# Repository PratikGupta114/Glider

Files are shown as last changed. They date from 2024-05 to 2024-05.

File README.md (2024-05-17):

<p align="center">
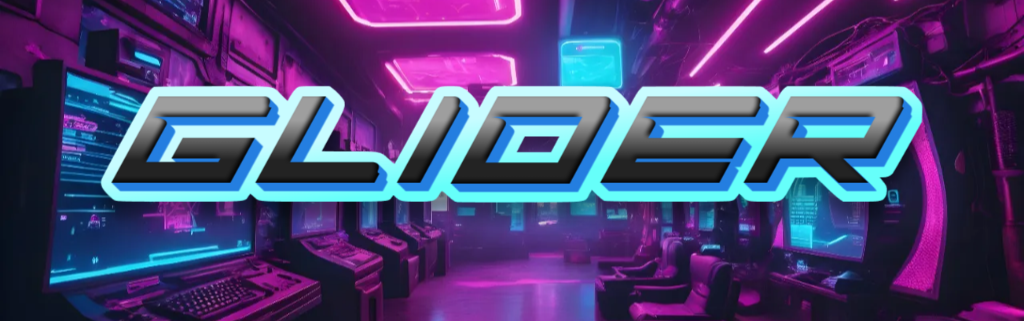
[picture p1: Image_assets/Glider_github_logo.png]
    
</p>

<p align="center">
    
</p>

<p align="center">
    
</p>

</br>

# Project Glider  
The official github repository for all Glider boards comprising Documentation, Pinouts & Example Sketches for all applications built using Glider boards.

The Glider Project is an initiative by the HyperDrive Community to make robotics accessible to everyone. It provides the necessary electronics for building quality robots and offers open-source code for projects that can be built using this board.

## A yet another Robo board ?

The Glider board solves a very common problem faced in robotics : 

> ***"Building robot boards from scratch"*** 

Although building a Robot board from scratch is fun, however it isn't necessary to **re-invent the wheel**.

Creating a DIY robot board is often tedious, time-consuming and error-prone, and such errors can be costly. Additionally, constructing the electronics for a robot is time-consuming. Even after successfully creating a DIY robot board on a zero-PCB (also known as a vero board), the board may lack sufficient connectivity, required for other projects.

## More about Glider boards 

Glider boards help makers and electronics hobbyists build amazing robots by providing connectivity for mutiple peripherals on a single pcb, such as:

* 2x 12V DC brushed motors (with connectivity for individual encoders for each motor)
Buttons
* 0.96" I2C OLED display
* MPU6050
* Buzzer & WS2812B Neopixels
* UART-based devices like HC-05
* Any 5V I2C-based peripheral
* In addition to providing connectivity with multiple peripherals, Glider boards offer reverse polarity protection at the source and support a wide voltage supply range of 7V to 20V.

Following are the links to the detailed documentation of all the Glider boards developed so far. 

- [Glider v1.0](./Docs/Glider_v1.0/doc.md) 

## Directory Structure

The following tree shows how the files are arranged in dedicated folders for easier navigation.

```
Glider/   
├─ 3D_models/  
│  ├─ [BOARD_NAME_1]/  
│  │  ├─ [STEP_FILE_1].step  
│  │  ├─ [STEP_FILE_2].step  
│  ├─ [BOARD_NAME_2]/  
├─ Code_examples/  
│  ├─ [BOARD_NAME_1]/  
│  │  ├─ Arduino_projects/  
│  │  │  ├─ [PROJECT_NAME_1]/  
│  │  │  ├─ [PROJECT_NAME_2]/  
│  │  ├─ PlatoformIO_projects/  
│  │  │  ├─ [PROJECT_NAME_1]/  
│  │  │  ├─ [PROJECT_NAME_2]/  
│  ├─ [BOARD_NAME_2]/  
├─ Docs/  
│  ├─ [BOARD_NAME_1]/  
│  │  ├─ [DOC_1].md  
│  │  ├─ [DOC_2].md  
│  ├─ [BOARD_NAME_2]/  
├─ Image_assets/  
LICENSE  
README.md  
```

## About Hyper Drive Community

Hyper Drive is a community of like-minded robotics enthusiasts who aim to guide and motivate young engineers in building and breaking barriers to create new robots.

We as community organizers, offer guidance in building autonomous bots and resources, such as articles, discussions, and expert mentorship, to those struggling to make their robots work.
HyperDrive\'s philosophy is centered around the idea of technology as a sport .We aim to bring together a diverse community of innovators, engineers, inventors, enthusiasts, and competitors under one roof.

We are passionate about motivating young engineers to create new robots, break through barriers, and strive for excellence in competition.
Join us today and discover the endless possibilities of robotics. 
No prior experience is necessary, and we welcome all levels of enthusiasts who share our commitment to learning and enthusiasm for engineering. HyperDrive is an initiative to provide you with what we never had during our time, 
and we invite you to be part of this exciting journey.

<br/>

<div align="center">
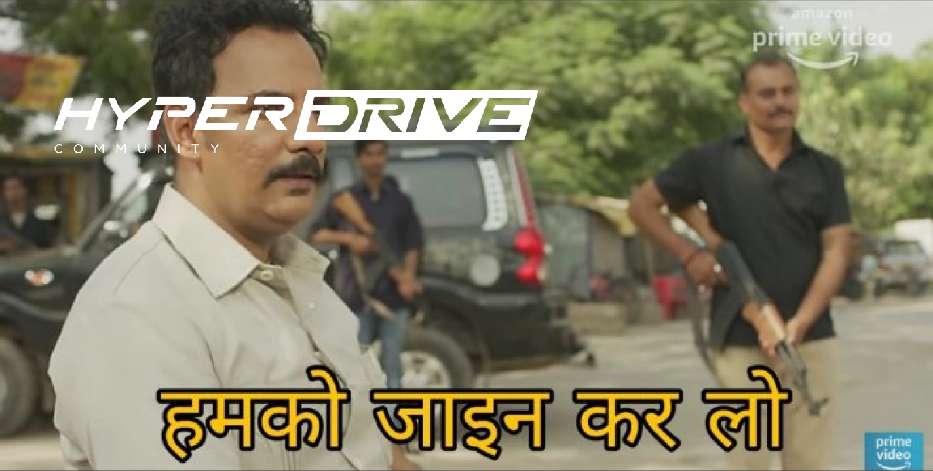
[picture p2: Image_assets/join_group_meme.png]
    
</div>

<br/>

<div align="center">  
    <a href="https://t.me/hyperdrivehd">
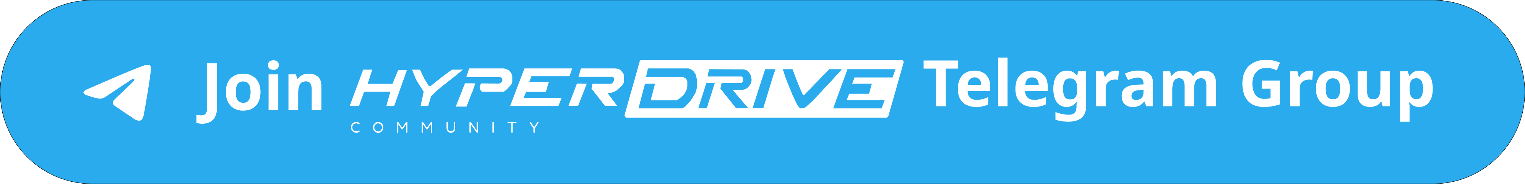
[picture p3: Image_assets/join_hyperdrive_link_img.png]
        
    </a>
</div>

## Author

<div align="center">
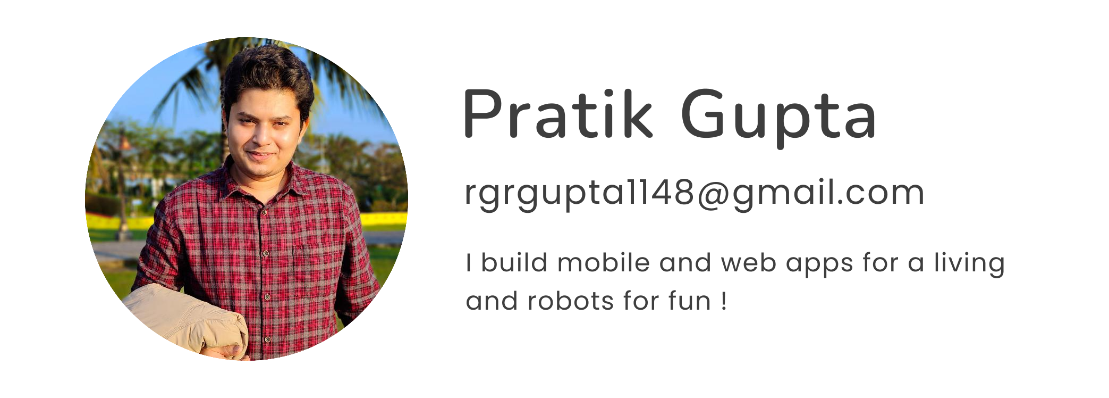
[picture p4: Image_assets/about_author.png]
    
</div>

<br/>
<br/>

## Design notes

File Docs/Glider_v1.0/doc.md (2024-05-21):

<div align="center"> 
     
</div>

</br>

# Glider v1.0

The first version of the Glider board series. A versatile, ESP32 powered, robot control board that allows one to build amazing robots. This board comes along with other components in form of a kit.

Apart from the roboboard, the other components include :

* [12 channel Line Sensor Array](#12-channel-line-sensor-array)
* [Parallel to Serial adapter for Line Sensor Array](#parallel-to-serial-adapter-for-line-sensor-array)
* [Neopixel Array & Buzzer board](#neopixel-array--buzzer-board)
* [OLED based GUI board](#oled-based-gui-board)

One of the common applications of this kit is Line Follower / Maze Solver robot. Apart from the components mentioned above, the kit also includes the necessary JST cables for enabling connectivity between the boards.

## The Roboboard 

<br/>

<p align="center">
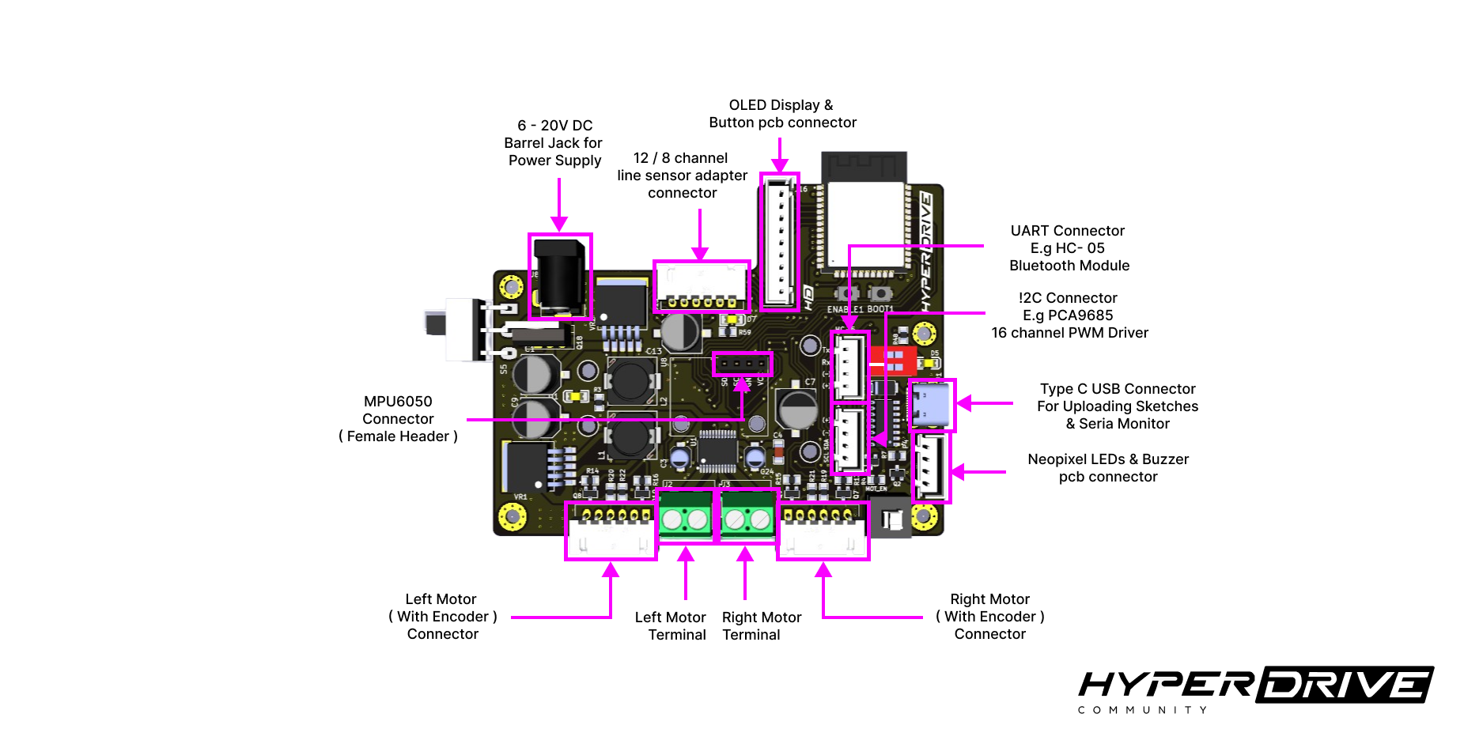
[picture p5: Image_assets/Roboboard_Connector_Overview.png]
    
</p>

<br/>

<p align="center">
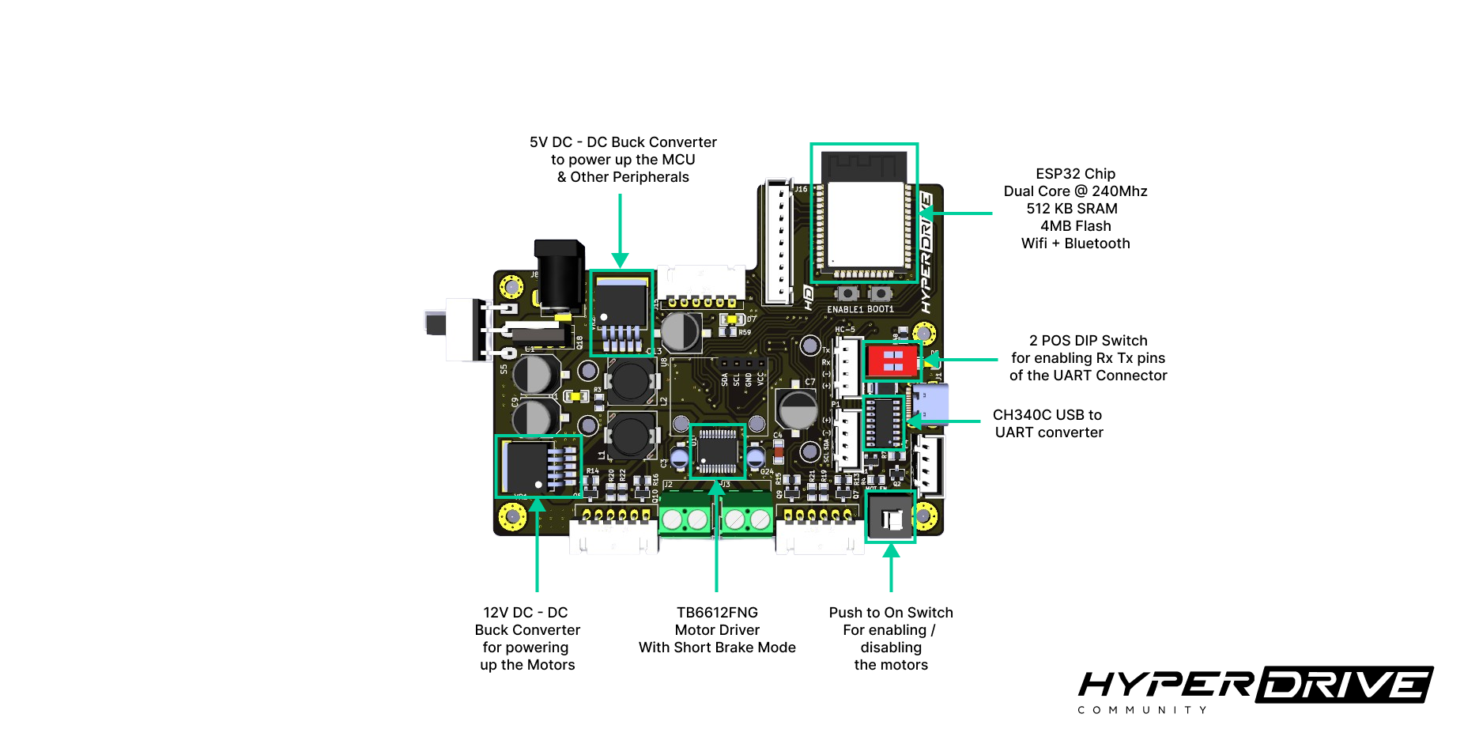
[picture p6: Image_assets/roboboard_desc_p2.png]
    
</p>

<br/>

Like most roboboards, the Glider v1.0 board too has a microcontroller and a motor driver However, this board has a lot more than just two of these components. Following are the core features of the roboboard : 

### 1. Wide range power supply 

this roboard has two buck converters : 12V and 5V. This way the board can be powered by upto 20V via the DC barrel jack.

### 2. USB Type C connectivity 

Unlike most arduino boards, like uno and nano, this has a type C USB connector for uploading the code to ESP32 and serial monitoring.

### 3. Mosfet based TB6612FNG motor driver

known for it's efficiency and decent current output of 1.2A per channel (continous & 3A peak), this board Has the widely used Tb6612fng motor driver integrated on board.

### 4. Encoder Motor Connectivity 

besides scew terminal blocks for controlling two independently running DC motors, the board has two connectors for motors with encoders. ***It's important to note that the first two pins of the connector (close to the terminal blocks) are connected to the screw terminals***.

### 5. Connectivity for MPU6050 

besides having encoders for obtaining odomentry data, the robot may need an IMU for better position estimation. The roboboard has a connectivity for an MPU6050, positioned in a way that the IMU is present at the center.

### 6. Connectivity for HC-05

ESP32 has an inbuilt WiFi and Bluetooth connectivity, however this communication is managed by the code. Such wireless connections may fail to persist after the micrcocontroller resets. To enble wireless debugging over bluetooth, the roboboard has the connectivity for an external module like the HC-05.

### 7. Neopixels (WS2812B RGB LED) array with buzzer 

most robots have to indicate the occurence of an event like detecting a checkpoint ( in case of a line follower ) or detecting a valid intersection ( in case of a maze solvinf robot). The kit comes along with a pcb strip which includes an array of 6 WS2812B leds and a buzzer for unique audio and visual indications.

### 8. Additional Connectivity for I2C based devices  

many projects may require the board to interface with external I2C based peripherals like sensors & motors controllers. Once such example could be PCA9685 for controlling multiple servo motors. Thus projects like a hexapod or a bipedal humanoid robot can also be built using this roboboard.

### 9. 3.3V to 5V transaltion  

Circuitry for conversion of logic level from 3.3v to 5v and vice-versa exists. All the pins the ESP32 board are connected to MOSFET based logic level converters / translators for safe interfaction with 5V logic level devices.

### 10.  GUI board with OLED display connectivity 

The kit includes a GUI board with 4 smd button arranged in Top, Left, Right & Bottom configuration. The board also includes the debouncing circuitry for each of the 4 buttons. Besides, the GUI board has a connectivity for a 0.96" OLED display, hence providing a GUI setup for users to make necessary configurations on the robot dynamically.   

### 11. Easy Motor Driver Control  

The board has a push to On / Off switch for enabling / disabling the motor driver. The TB6612FNG has a STBY pin that allows it to be enabled / disabled by applying +5V digital logic ( 1 or 0). This pin is connected to +5V via a push to on / off switch that haults the motors without affecting the microcontroller's operation and powering off the entire board. This feature comes handy in many scenarious specially in case of a Line Follower Robot.  

### 12. Firm Connections to ensure reliabiity 

Unline most arduino based DIY projects, the use of Jumper / dupont wires may often lead to undesirable behavior as such connecting wires are prone to wearing out over multiple connections / disconnections. Japan Solderless Terminals (JST) connectors on the other hand are widely used in the industry, specially in most electronics based products due to their reliable nature. Leveraging this reliability and firm connectivity JST connectors are used throughout to allow firm connections as jumper wires are often fragile and wear out over time.

## Roboboard ESP32 pin allocation table

The following table describes which of the ESP32 GPIO pins are allocated to the onboard peripherals, however one can refer to the [Diagram based pinout](/Image_assets/roboboard_pinout.png) for convenience

| ESP32 pin in ESP-IDF | Peripheral  |  3.3V to 5V Translation  |
| --- | --- | ---  |
<br/><span style="font-weight:bold;font-size:1.15em">Motor Driver (TB6612FNG)</span>
|   ```GPIO_NUM_26```  | AIN1 | Yes    |
|   ```GPIO_NUM_25```  | AIN2 | Yes    | 
|   ```GPIO_NUM_32```  | BIN2 | Yes    |
|   ```GPIO_NUM_33```  | BIN1 | Yes    |
|   ```GPIO_NUM_19```  | PWMA | Yes    |
|   ```GPIO_NUM_18```  | PWMB | Yes    |
<br/> <span style="font-weight:bold;font-size:1.15em">Line Sensor Adapter connectivity port</span>
|   ```GPIO_NUM_27```  | LOAD_PIN           | Yes  | 
|   ```GPIO_NUM_4```   | CLOCK_ENABLE_PIN   | Yes  |
|   ```GPIO_NUM_17```  | DATA_PIN           | Yes  |
|   ```GPIO_NUM_16```  | CLOCK_PIN          | Yes  |
<br/> <span style="font-weight:bold;font-size:1.15em">On board peripherals</span>
|   ```GPIO_NUM_2```   | BLUE_LED | No |
<br/> <span style="font-weight:bold;font-size:1.15em">Indication Board connectivity port</span>
|   ```GPIO_NUM_12```  | BUZZER             | Yes  |
|   ```GPIO_NUM_23```  | NEOPIXEL_LED_PIN   | Yes  |
<br/> <span style="font-weight:bold;font-size:1.15em">GUI Board connectivity port</span>
|   ```GPIO_NUM_36```  | BUTTON_LEFT    | No   |        
|   ```GPIO_NUM_39```  | BUTTON_RIGHT   | No   |       
|   ```GPIO_NUM_34```  | BUTTON_TOP     | No   |       
|   ```GPIO_NUM_35```  | BUTTON_BOTTOM  | No   |      
<br/> <span style="font-weight:bold;font-size:1.15em">Encoders port</span>
|   ```GPIO_NUM_15```  | LEFT_MOTOR_ENC_A   | Yes  |
|   ```GPIO_NUM_5```   | LEFT_MOTOR_ENC_B   | Yes  |
|   ```GPIO_NUM_13```  | RIGHT_MOTOR_ENC_A  | Yes  |
|   ```GPIO_NUM_14```  | RIGHT_MOTOR_ENC_B  | Yes  |
<br/> <span style="font-weight:bold;font-size:1.15em">I2C ports</span>
|   ```GPIO_NUM_21```  | SDA_PIN | Yes |
|   ```GPIO_NUM_22```  | SCL_PIN | Yes |
<br/> <span style="font-weight:bold;font-size:1.15em">UART0 ( Serial0 )</span>
|   ```GPIO_NUM_1```  | TXD_0   | No   |
|   ```GPIO_NUM_3```  | RXD_0   | No   |

<br/>

## 12 channel Line Sensor Array

<br/>

<p align="center">
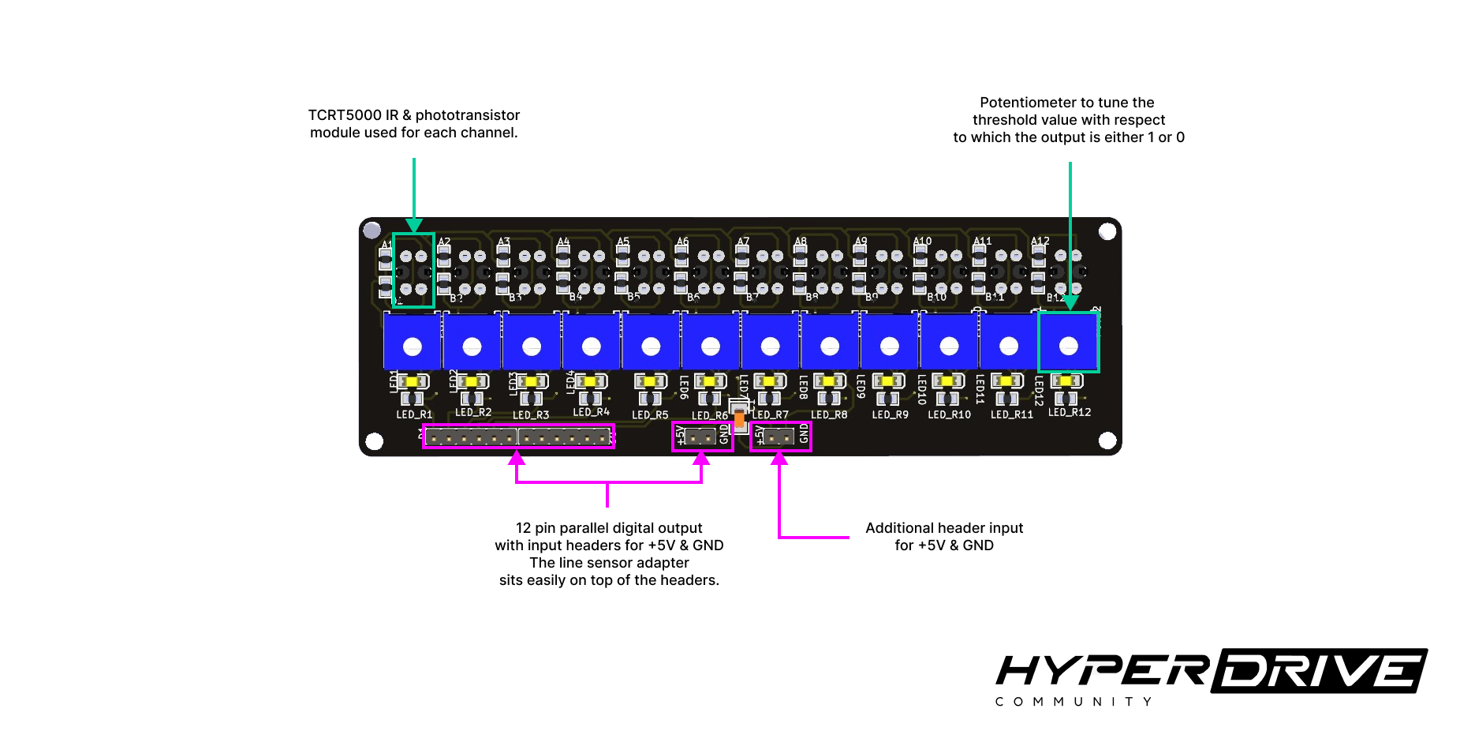
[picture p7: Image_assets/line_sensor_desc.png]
    
</p>

<br/>

This sensor array has 12 individual sensors that output either +5V / 0V (digital 1 / 0) depending on how white / black the surface beneath the sensor is. The threshold above which the sensor outputs 1, is adjusted by the corresponding potentiometer. This way the Line sensor array outputs a 12 bit digital data.

Since the sensor ouputs 1 for a white surface and 0 for black surface, then sliding the sensor above a white line ( which is drawn above the black surface ), thick enough to cover 2 sensors, them the 12 bit output from the sensors looks something like : 

```
001100000000
000110000000
000011000000
000001100000
000000110000
000000011000
000000001100
```

## Parallel to Serial adapter for Line Sensor Array

A microcontroller may not have enough digital pins to read all the 12 bits of data from the line sensor array. This parallel output from the line sensor array must be converted to serial data such that the microcontroller can interface with the sensor using only a few pins. 
One such device for reading multiple inputs, using only 4 gpio pins of a microcontroller, is a shift register.  

For instance, an 8 bit shift regsiter, like 74HC165, can read upto 8 digital inputs. Hence for reading the 12 bit data from the line sensor array, at least two of these 8-bit shift registers will be required.
74HC165 shift registers have the ability to be cascaded with another shift register in a way that using only one data pin, a microcontroller can read data from all the shift registers. 

The adapter pcb houses two *daisy chained* shift registers and the serial output connector has the necessary pins that allows any microcontroller to read the Serial data. 
As shown in the [pinout](/Image_assets/adapter_pinout.png), the adapter outputs 16-bit data out of which 12 bits in the middle represent the digital output from the line sensor array and two bits from either side are dummy bits.

<br/>

<p align="center">
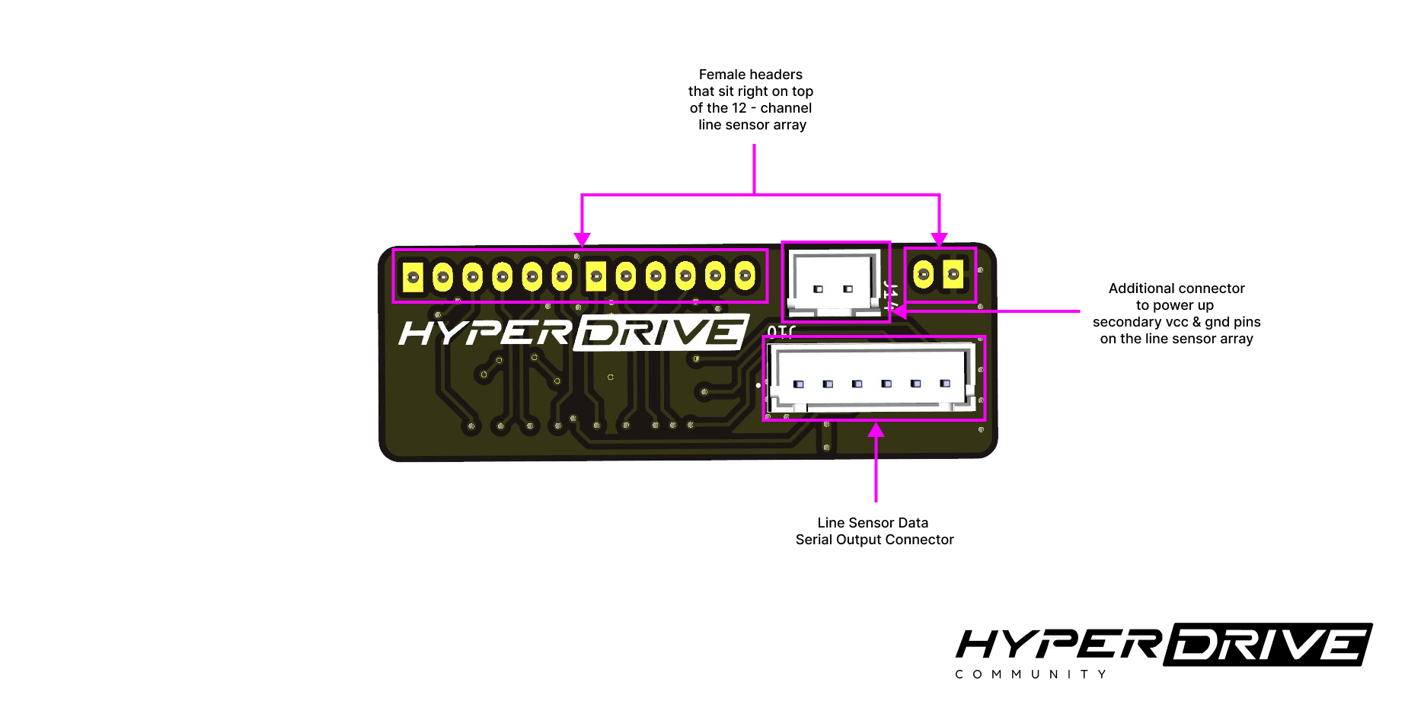
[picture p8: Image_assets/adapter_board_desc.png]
    
</p>

## Neopixel Array & Buzzer board

This board is a smalll pcb strip which has 6 WS2812B Neopixel RGB LEDs and a 5V buzzer. As shown in the [pinout](/Image_assets/indication_board_pinout.png), the connector with 4 pins acts as the input for the first neopixel leds and the buzzer. This board also has an output to extend the chain of LED array. Thus allowing an LED string to be connected with this board. However it is important to note that this board may have a limited ouput power. Thus limiting the number of LEDs that can be extended with this board.  

<br/>

<p align="center">
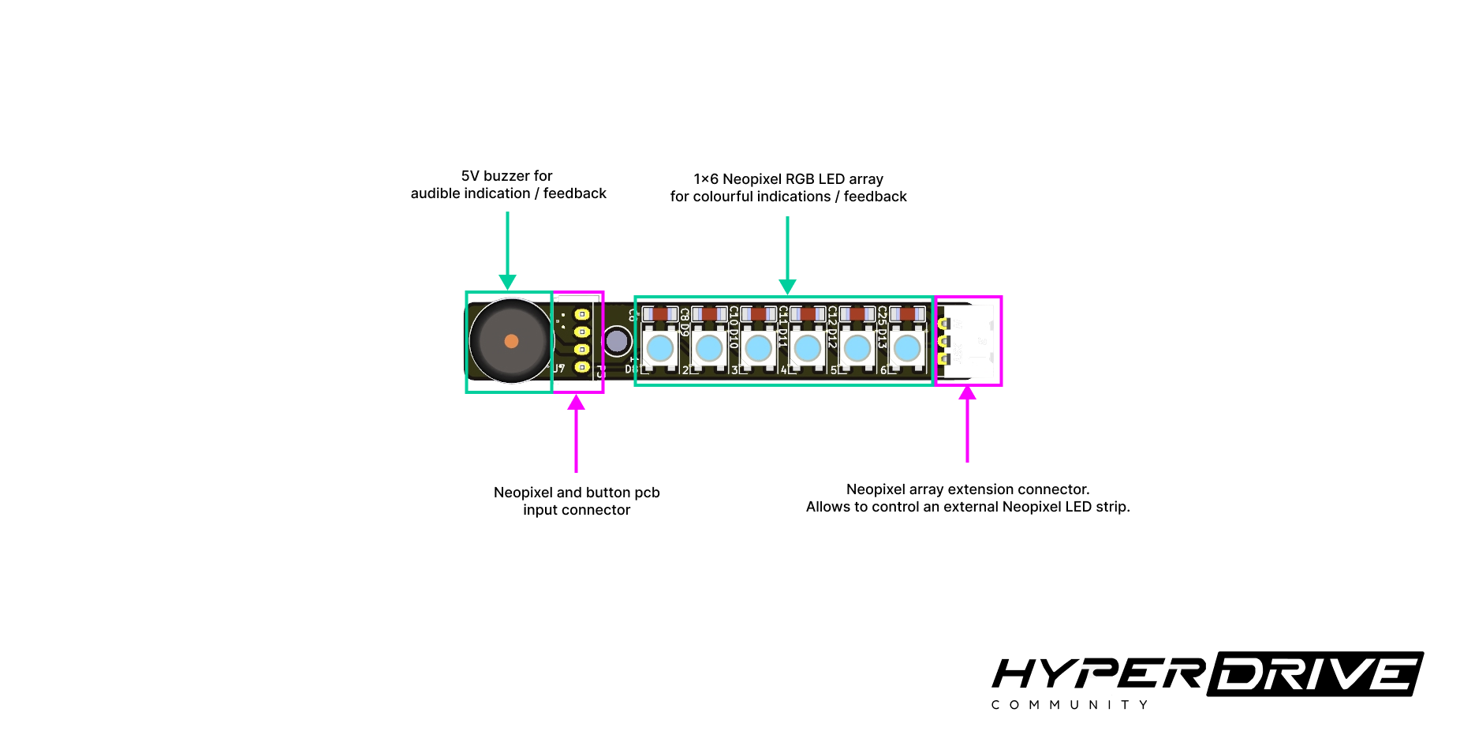
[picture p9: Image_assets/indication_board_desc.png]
    
</p>

<br/>

## OLED based GUI board

A robot built with the Glider v1.0 may require configurations to made dynamically, in other words, configurations without re-uplaoding the firmware. Such frequent configurations can be made either wirelessly, or via an onboard GUI. This roboboard is capbale of implementing both the approach. However, an onboard GUI doesn't always require a persistent wireless connection.

This GUI board has 4 smd button which can help users to navigate through a menu, which can possibly be displayed on a SSD1306 OLED display. To ensure robustness and utilize the pcb-real estate, this board also includes required circuitry for button debouncing allowing interrupt based programs can run flawlessly.

On the left side of the pcb, female headers are present to allow SSD1306 based OLED displays to connect. Therefore this board serves most functionalities of a GUI board. Besides, the outline of this board is designed in such a way that it can be stacked up on the robobaord using 4 nuts, bolts, and spacers and connect with the roboboard via a 9 pin JST cable. Please check the [pinout](/Image_assets/gui_board_pinout.png) for the gui board connector.

<br/>

<p align="center">
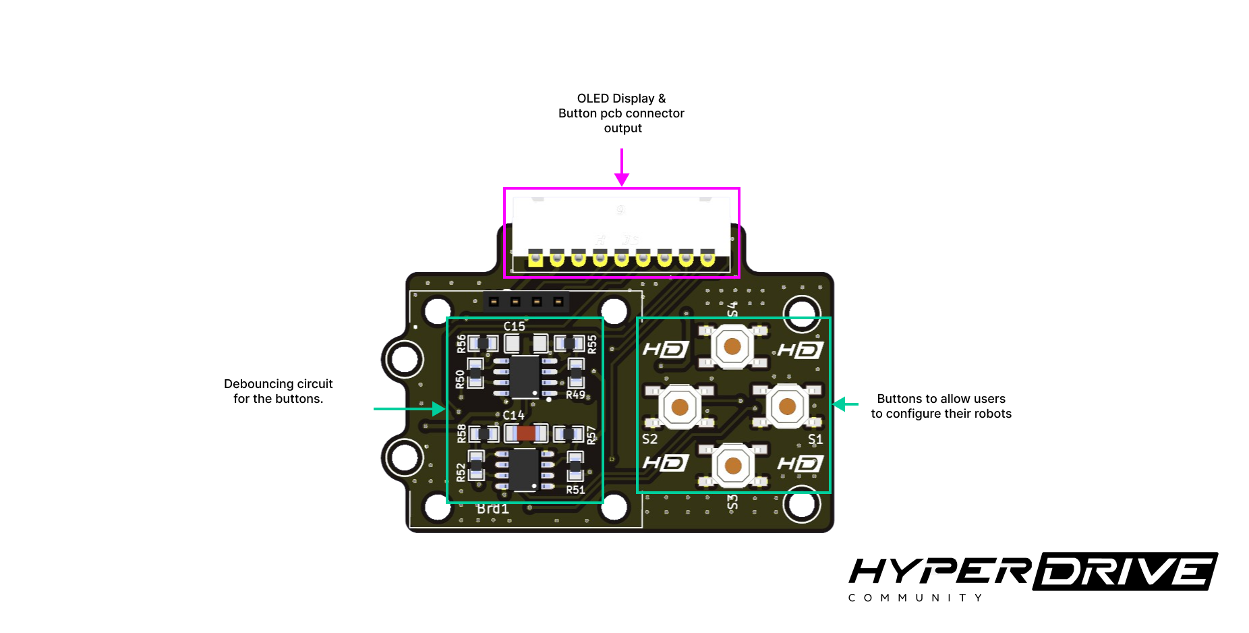
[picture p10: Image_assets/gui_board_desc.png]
    
</p>

<br/>

## Pinouts 

Following are the links to the images that describe each of the pins of the connectors on the respective boards : 

1. [Roboboard pinout](/Image_assets/roboboard_pinout.png)
2. [Line sensor adapter pinout](/Image_assets/adapter_pinout.png)
3. [Indication pinout](/Image_assets/indication_board_pinout.png)
4. [GUI board pinout](/Image_assets/gui_board_pinout.png)

## Projects 

Unlike most roboboards designed for specific project. The Glider v1.0 board allows users to build several other robots like : 
* Hexapod 
* Quadcopter
* Self-balancing robot

However, Line Following robots are the entry point to get started with robotics. The kit comes along with a 12 channel line sensor array which allows makers to build a Line Follower Robot. This repository contains the [source code for an LFR](/Code_examples/Glider_v1.0/PlatformIO_projects/Line_Follower_Robot/), as a platformIO project, and the same for other projects to get started.

Line Follower Robot In Action

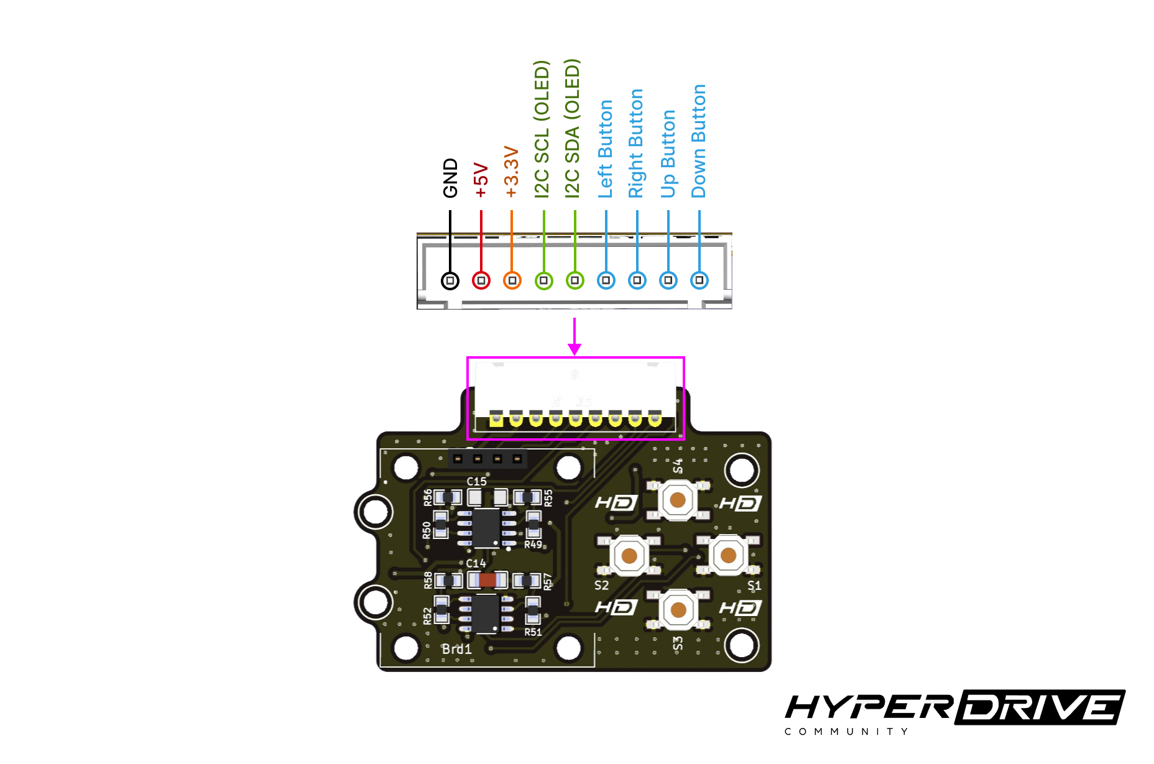
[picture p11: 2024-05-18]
Image_assets/gui_board_pinout.png

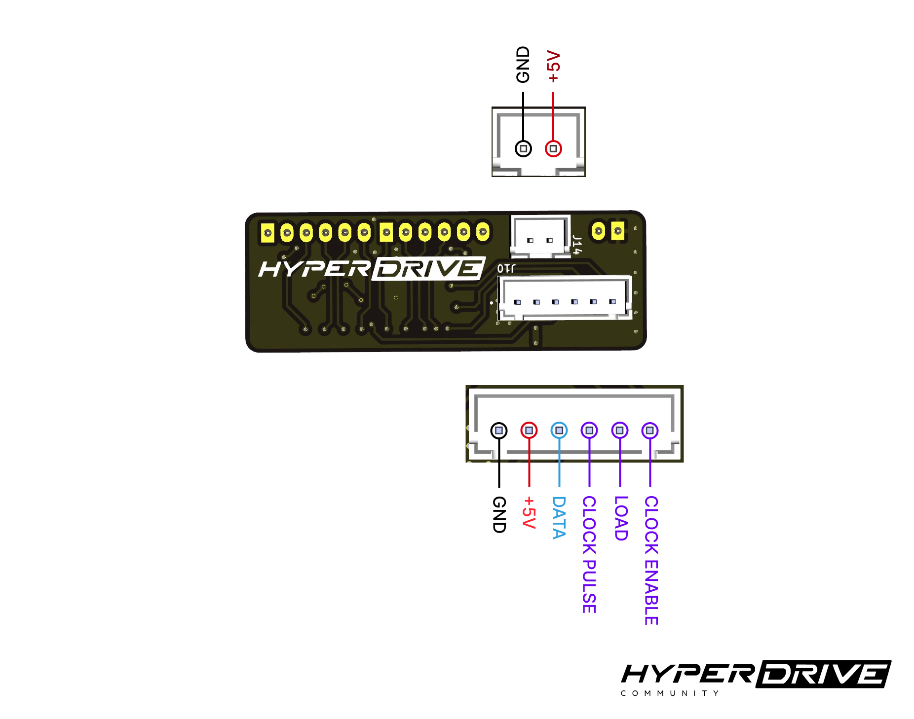
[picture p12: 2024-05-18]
Image_assets/adapter_pinout.png

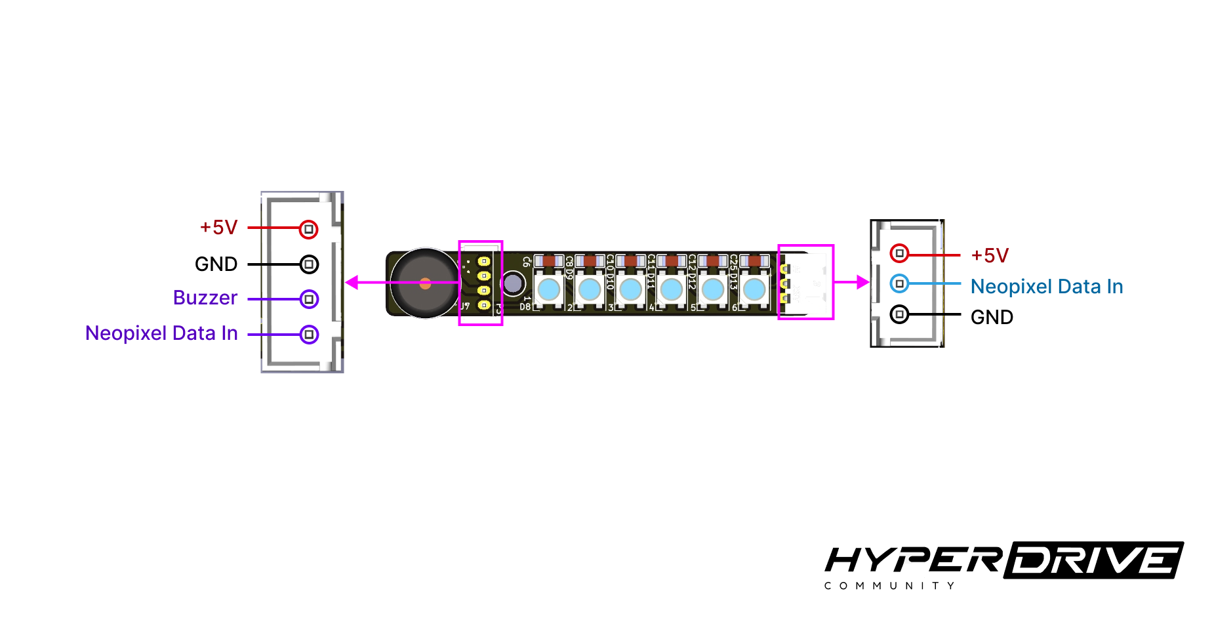
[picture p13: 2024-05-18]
Image_assets/indication_board_pinout.png

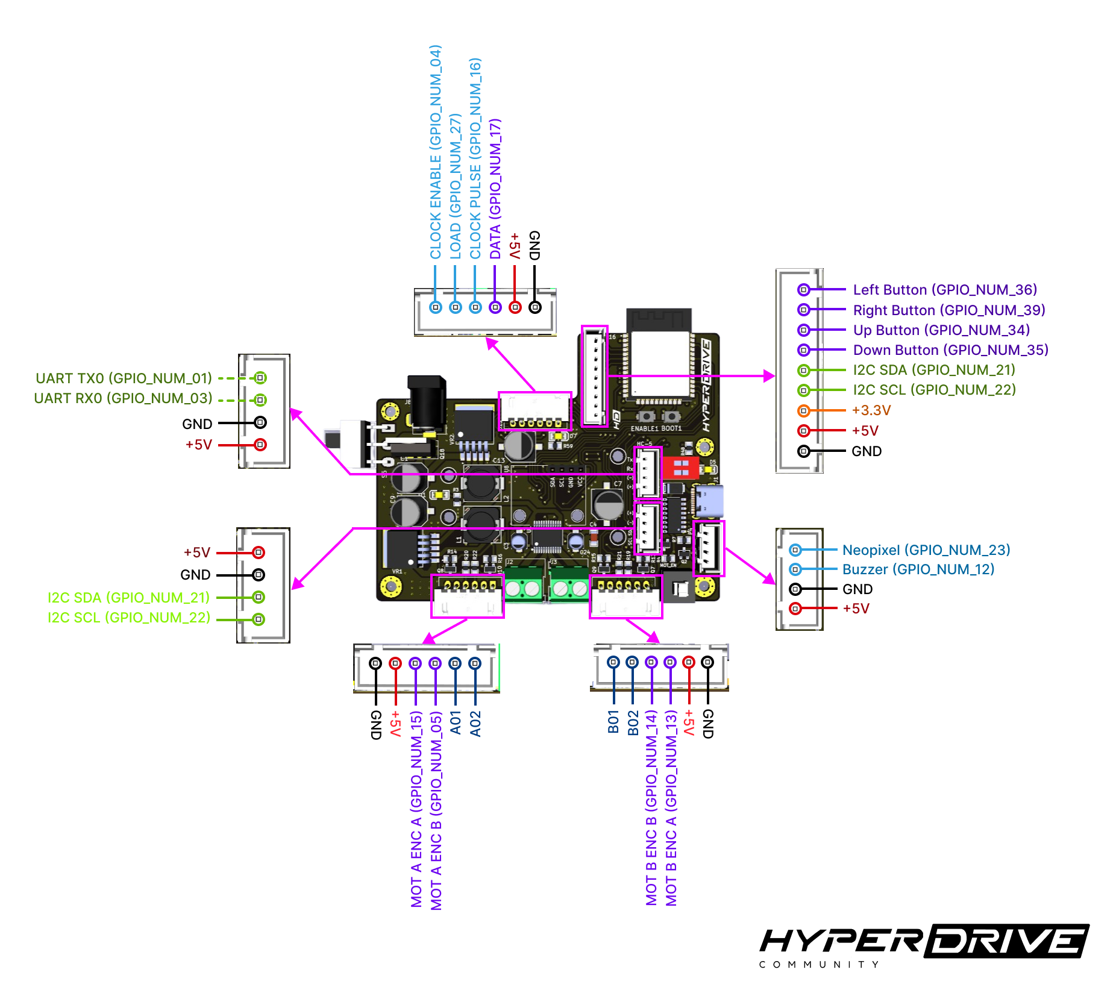
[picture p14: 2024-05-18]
Image_assets/roboboard_pinout.png

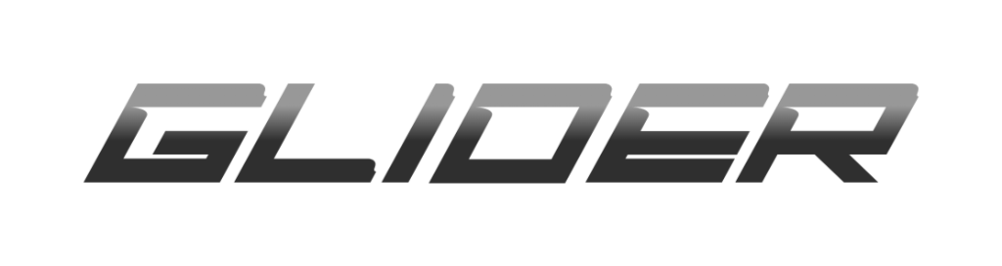
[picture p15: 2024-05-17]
Image_assets/gLIDER-15-05-2024 (2).png

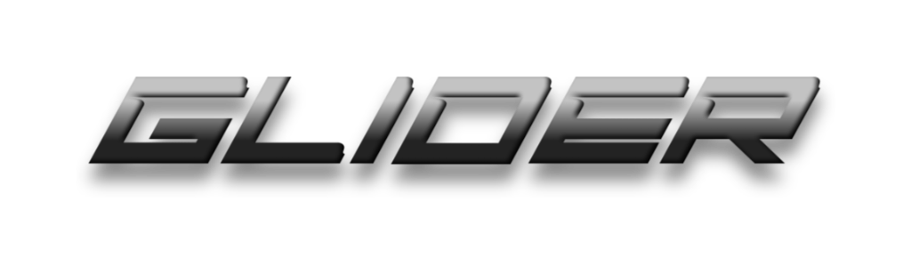
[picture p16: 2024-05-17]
Image_assets/gLIDER-15-05-2024 (3).png

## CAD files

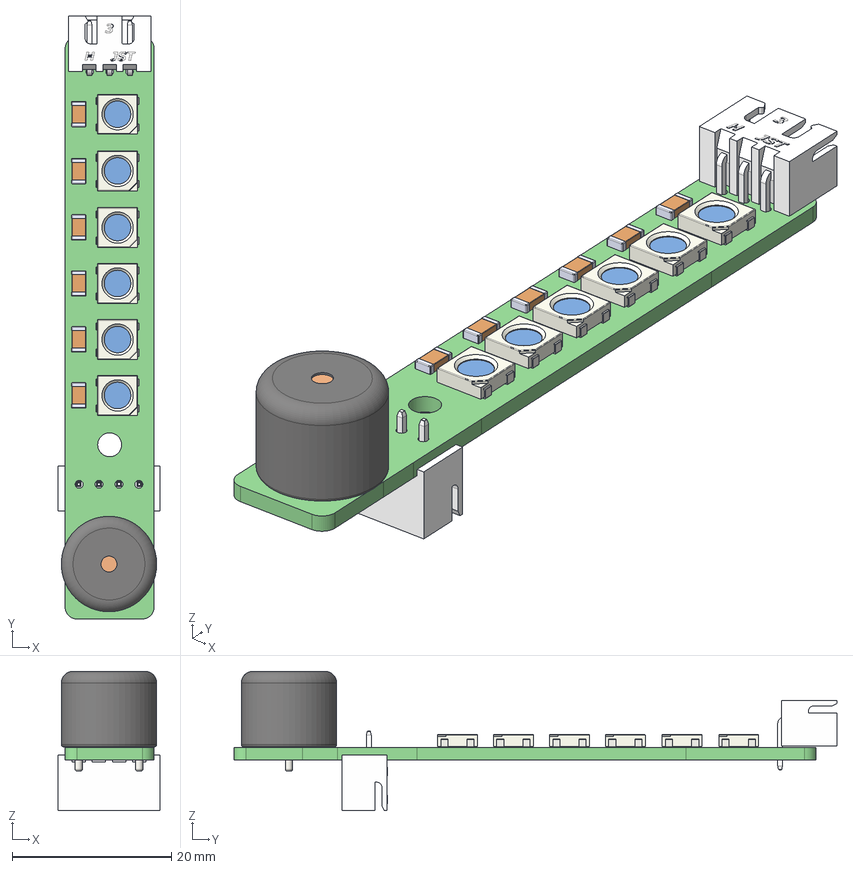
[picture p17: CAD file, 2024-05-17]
3D_models/Glider_v1.0/LFRControlBoard_Indicator.step
12.9 x 75.8 x 17.5 mm

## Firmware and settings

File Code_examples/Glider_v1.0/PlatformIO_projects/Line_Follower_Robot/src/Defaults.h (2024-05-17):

#ifndef DEFAULTS_H
#define DEFAULTS_H

#define OUT_OF_LINE_ERROR_VALUE 20
#define LOOP_ESCAPE_ERROR_VALUE 3

// The duration in milliseconds for which the short brake is applied.
#define BRAKE_DURATION_MILLIS 100

#define DEFAULT_LOOP_DELAY 0
#define DEFAULT_KP 0
#define DEFAULT_KI 0
#define DEFAULT_KD 0
#define DEFAULT_MOTOR_SPEED 0
#define WHITE_LINE_BLACK_TRACK 0
#define BLACK_LINE_WHITE_TRACK 1

// Percentage by which the base motor speed reduces
// whenever the robot rotates clockwise / counter clockwise.
#define TURN_SPEED_REDUCTION_PERCENT 10

// The duration in milliseconds for which the robot moves straight to
// confirm the presence of a stop patch.
#define STOP_CHECK_DELAY 150

#endif

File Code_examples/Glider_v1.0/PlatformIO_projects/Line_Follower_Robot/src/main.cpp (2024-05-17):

#include <Arduino.h>
#include "PinDefinitions.h"
#include "Config.h"
#include "Defaults.h"
#include "GlobalVariables.h"
#include "MotorControl.h"
#include "Sensor.h"
#include "Wire.h"
#include "FastLED.h"

// Include ArduinoJson.h only when bluetooth logging / tuning is enabled.
#if BLUETOOTH_LOGGING_ENABLED == 1 || BLUETOOTH_TUNING_ENABLED == 1
#include <ArduinoJson.h>

#define TX_DOC_MAX_DATA_LEN 256
#define RX_DOC_MAX_DATA_LEN 192

// Inlcude BluetoothSerial.h only when the config macro for using the inbuilt bluetooth is set to 1
#if USE_INBUILT_BLUETOOTH == 1
#include <BluetoothSerial.h>

#endif
#endif

// Macro definitions for commonly occurring conditions.
// These macro definitions make the code more readable.
#define MID_8_SENSORS_HIGH (s3 == 1 && s4 == 1 && s5 == 1 && s6 == 1 && s7 == 1 && s8 == 1 && s9 == 1 && s10 == 1)
#define MID_8_SENSORS_LOW (s3 == 0 && s4 == 0 && s5 == 0 && s6 == 0 && s7 == 0 && s8 == 0 && s9 == 0 && s10 == 0)

#define MID_6_SENSORS_HIGH (s4 == 1 && s5 == 1 && s6 == 1 && s7 == 1 && s8 == 1 && s9 == 1)
#define MID_6_SENSORS_LOW (s4 == 0 && s5 == 0 && s6 == 0 && s7 == 0 && s8 == 0 && s9 == 0)

// #########################################################################################################################
///////////////////////////////////////////////     VARIABLE DEFINITIONS     ///////////////////////////////////////////////
// #########################################################################################################################

#if BLUETOOTH_LOGGING_ENABLED == 1
StaticJsonDocument<TX_DOC_MAX_DATA_LEN> txDoc;
#endif
#if BLUETOOTH_TUNING_ENABLED == 1
StaticJsonDocument<RX_DOC_MAX_DATA_LEN> rxDoc;
#endif

int Kp = DEFAULT_KP;
int Ki = DEFAULT_KI;
int Kd = DEFAULT_KD;
int baseMotorSpeed = DEFAULT_MOTOR_SPEED;
int loopDelay = DEFAULT_LOOP_DELAY;
int error = 0;
int leftMotorOffset = 0;
int rightMotorOffset = 0;
int P = 0;
int I = 0;
int D = 0;
int error_dir = 0;
int previousError = 0;
int PID_value = 0;

// Make sure to update this variable according to the type of track the LFR is about to run on.
// When the macro for enabling inversion is set to 1, this variable updates itself automatically.
uint8_t trackType = BLACK_LINE_WHITE_TRACK;

CRGB leds[NUM_LEDS];

// Define the Inbuilt bluetooth object only when bluetooth tuning / logging config macro is set to 1
// and the default bluetooth is to be used.
#if ((BLUETOOTH_LOGGING_ENABLED == 1 || BLUETOOTH_TUNING_ENABLED == 1) && USE_INBUILT_BLUETOOTH == 1)
BluetoothSerial SerialBT;
#endif

// #########################################################################################################################
///////////////////////////////////////////////     FUNCTION DEFINITIONS     ///////////////////////////////////////////////
// #########################################################################################################################

/**
 * @brief 	This function is called when inversion is enabled and the trackType variable changes to
 * 			the type different from the default value.
 * 			In this case, 2 out of 6 LEDs of the Neopixel array indicate red for inversion and the
 * 			rest are for indicating checkpoints.
 */
void indicateInversionOn()
{
	leds[0] = CRGB(255, 0, 0);
	leds[1] = CRGB(255, 0, 0);
	FastLED.show();
}

/**
 * @brief 	Clear all indications for inversion only.
 */
void indicateInversionOff()
{
	leds[0] = CRGB(0, 0, 0);
	leds[1] = CRGB(0, 0, 0);
	FastLED.show();
}

/**
 * @brief 	This function is called when an event occurs. In this case, the event is checkpoint detection
 * 			4 out of 6 LEDs of the neopixel array indicate a color diffrent from the color
 * 			used for indicating inversion.
 */
void indicateOn()
{
	digitalWrite(BUZZER, HIGH);
	digitalWrite(BLUE_LED, HIGH);
	leds[3] = CRGB(80, 0, 255);
	leds[4] = CRGB(80, 0, 255);
	leds[2] = CRGB(80, 0, 255);
	leds[5] = CRGB(80, 0, 255);
	FastLED.show();
}

/**
 * @brief	Clear all indications for event only
 *
 */
void indicateOff()
{
	digitalWrite(BUZZER, LOW);
	digitalWrite(BLUE_LED, LOW);
	leds[2] = CRGB(0, 0, 0);
	leds[3] = CRGB(0, 0, 0);
	leds[4] = CRGB(0, 0, 0);
	leds[5] = CRGB(0, 0, 0);
	FastLED.show();
}

/**
 * @brief 	The first step of an LFR's algorithm.
 * 			This function does the following :
 * 				1. Updates the error variable,
 * 				2. Keep a track of; on which side of the sensor was the line was detected ( error_dir )
 *				3. Indicate On / Off for checkpoint & inversion
 *				4. based on the sensor readings check if the robot went out of the line or did it just come across a stop patch
 *			Logic for traversing through maze like intersections can be implemented in this function
 */
void readSensors()
{

	uint16_t sensorData = getSensorReadings();
	error = getCalculatedError(0);

	// left most sensor value
	int s1 = (sensorData & (1 << 13)) >> 13;

	int s2 = (sensorData & (1 << 12)) >> 12;
	int s3 = (sensorData & (1 << 11)) >> 11;
	int s4 = (sensorData & (1 << 10)) >> 10;
	int s5 = (sensorData & (1 << 9)) >> 9;
	int s6 = (sensorData & (1 << 8)) >> 8;
	int s7 = (sensorData & (1 << 7)) >> 7;
	int s8 = (sensorData & (1 << 6)) >> 6;
	int s9 = (sensorData & (1 << 5)) >> 5;
	int s10 = (sensorData & (1 << 4)) >> 4;
	int s11 = (sensorData & (1 << 3)) >> 3;

	// right most sensor value
	int s12 = (sensorData & (1 << 2)) >> 2;

	if (s1 != s12)
		error_dir = s1 - s12;

	if (MID_6_SENSORS_HIGH)
		indicateOn();
	else
		indicateOff();

	if (trackType == WHITE_LINE_BLACK_TRACK)
		indicateInversionOn();
	else
		indicateInversionOff();

	// When all the sensors indicate LFR is out of line
	if (sensorData == 0b0000000000000000)
	{
		// Moved out of the line
		if (error_dir < 0)
			error = OUT_OF_LINE_ERROR_VALUE;
		else if (error_dir > 0)
			error = -1 * OUT_OF_LINE_ERROR_VALUE;
	}
	// When all the sensors indicate LFR is above a patch.
	else if (sensorData == 0b0011111111111100)
	{
		// This is a stop
		moveStraight(baseMotorSpeed, baseMotorSpeed);
		delay(STOP_CHECK_DELAY);
		uint16_t sensorDataAgain = getSensorReadings();
		if (sensorDataAgain == 0b0011111111111100)
		{
			indicateOff();
			shortBrake(1000);
			stop();
			delay(10000);
		}
	}

#if BLUETOOTH_LOGGING_ENABLED == 1

#if USE_SERIAL_BLUETOOTH == 1
	char ss[16];
	// char output[TX_DOC_MAX_DATA_LEN];

	sprintf(ss, "" TWELVE_BIT_SENSOR_PATTERN, TO_TWELVE_BIT_SENSOR_PATTERN(sensorData));

	// txDoc["di"] = String(ss);
	// serializeJson(txDoc, output);
	// Serial.println(output);
	// txDoc.clear();

	Serial.print(F("I|Readings : "));
	Serial.print(String(ss));
	Serial.print(F(" | Error : "));
	Serial.print(error);
	Serial.print(F(" | Inv : "));
	Serial.println(isInverted == WHITE_LINE_BLACK_TRACK ? F("WHITE_LINE_BLACK_TRACK") : F("BLACK_LINE_WHITE_TRACK"));
#endif

#if USE_INBUILT_BLUETOOTH == 1
	SerialBT.printf("I|Readings : " TWELVE_BIT_SENSOR_PATTERN "| Error : %d | Inv :  %s\n",
					TO_TWELVE_BIT_SENSOR_PATTERN(sensorData),
					error, trackType == WHITE_LINE_BLACK_TRACK ? "WHITE_LINE_BLACK_TRACK" : "BLACK_LINE_WHITE_TRACK");
#endif

#endif
}

/**
 * @brief	Calculated the PID_Value based of the error calculated in the previous step.
 * 			The PID valus acts as a speed difference to be added between the left and right motors.
 */
void calculatePID()
{
	P = error;

	if (error == 0)
		I = 0;
	else
		I = I + error;

	I = constrain(I, -200, 200);

	D = error - previousError;
	PID_value = (Kp * P) + (Ki * I) + (Kd * D);
	PID_value = constrain(PID_value, -255, 255);
	previousError = error;
}

/**
 * @brief 	Calculates the individual speeds of left and right motor (between 0 - 255) after introducing
 * 			the PID_Value as an addition / subtraction for either of the left & right motor speeds
 * 			depending on the sign of the PID_Value.
 * 			Besides, this function also makes the robot turn clockwise / counter clockwise if a special
 * 			value is assigned to the error variable, as a routine to make the LFR get back to the line.
 */
void controlMotors()
{
	if (error == OUT_OF_LINE_ERROR_VALUE)
	{
#if BLUETOOTH_LOGGING_ENABLED == 1 && USE_SERIAL_BLUETOOTH == 1
		Serial.println(F("E|Turning Clockwise  : "));
#endif
#if BLUETOOTH_LOGGING_ENABLED == 1 && USE_INBUILT_BLUETOOTH == 1
		SerialBT.println(F("E|Turning Clockwise  : "));
#endif
#if BRAKING_ENABLED == 1
		shortBrake(BRAKE_DURATION_MILLIS);
#endif
		// rotate clockwise until the sensors read a line somewhere in the center.
		uint8_t sensorReadings = getSensorReadings();
		while (isOutOfLine(sensorReadings))
		{
			turnCW(baseMotorSpeed - leftMotorOffset, baseMotorSpeed - rightMotorOffset);
			sensorReadings = getSensorReadings();
		}
// #if BRAKING_ENABLED == 1
// 		shortBrake(BRAKE_DURATION_MILLIS);
// #endif
#if GAPS_ENABLED == 1
		// Check line 300
		error_dir = 0;
#endif
	}
	else if (error == (-1 * OUT_OF_LINE_ERROR_VALUE))
	{
#if BLUETOOTH_LOGGING_ENABLED == 1 && USE_SERIAL_BLUETOOTH == 1
		Serial.println(F("E|Turning Counter Clockwise  : "));
#endif
#if BLUETOOTH_LOGGING_ENABLED == 1 && USE_INBUILT_BLUETOOTH == 1
		SerialBT.println(F("E|Turning Counter Clockwise  : "));
#endif

#if BRAKING_ENABLED == 1
		shortBrake(BRAKE_DURATION_MILLIS);
#endif
		// rotate clockwise until the sensors read a line somewhere in the center.
		uint8_t sensorReadings = getSensorReadings();
		while (isOutOfLine(sensorReadings))
		{
			turnCCW(baseMotorSpeed - leftMotorOffset, baseMotorSpeed - rightMotorOffset);
			sensorReadings = getSensorReadings();
		}
// #if BRAKING_ENABLED == 1
// 		shortBrake(BRAKE_DURATION_MILLIS);
// #endif

// If gaps are enabled in this project, then the error_dir is set to 0 as soon as
// the lfr get back to the line. This way a robot can traverse through line break
// but may get out of dead ends.
#if GAPS_ENABLED == 1
		error_dir = 0;
#endif
	}
	else
	{
		int leftMotorSpeed = baseMotorSpeed + PID_value - leftMotorOffset;
		int rightMotorSpeed = baseMotorSpeed - PID_value - rightMotorOffset;

		moveStraight(leftMotorSpeed, rightMotorSpeed);

		// Additional delay imposed to make the Derivative component's impact more significant.
		// This variable can be tuned dynamically
		if (D != 0)
			delay(loopDelay);
	}
}

// #########################################################################################################################
//////////////////////////////////////////////////////     SETUP     //////////////////////////////////////////////////////
// #########################################################################################################################

void setup()
{
	pinMode(LEFT_MOTOR_PIN_1, OUTPUT);
	pinMode(LEFT_MOTOR_PIN_2, OUTPUT);
	pinMode(RIGHT_MOTOR_PIN_1, OUTPUT);
	pinMode(RIGHT_MOTOR_PIN_2, OUTPUT);
	pinMode(LEFT_MOTOR_PWM_PIN, OUTPUT);
	pinMode(RIGHT_MOTOR_PWM_PIN, OUTPUT);

	pinMode(BLUE_LED, OUTPUT);
	pinMode(BUZZER, OUTPUT);

#if BLUETOOTH_LOGGING_ENABLED == 1 || BLUETOOTH_TUNING_ENABLED == 1

#if USE_SERIAL_BLUETOOTH == 1
	Serial.begin(SERIAL_BAUD_RATE);
#endif

#if USE_INBUILT_BLUETOOTH == 1
	SerialBT.setPin("9637");
	SerialBT.begin("Glider v1.0");
#endif

#endif

	FastLED.addLeds<WS2812, NEOPIXEL_LED_PIN, GRB>(leds, NUM_LEDS);
}

// #########################################################################################################################
//////////////////////////////////////////////////////     LOOP     ///////////////////////////////////////////////////////
// #########################################################################################################################

void loop()
{

#if BLUETOOTH_TUNING_ENABLED == 1

	// Sample Message format
	// {"P":36,"I":60,"D":38,"ms":100,"de":9}

#if USE_SERIAL_BLUETOOTH == 1
	if (Serial.available())
	{
		Serial.flush();
		String data = Serial.readStringUntil('\n');

		Serial.print(F("I|Data received : "));
		Serial.println(data);

		DeserializationError error = deserializeJson(rxDoc, data);

		if (error)
		{
			Serial.print(F("E|deseriaize json failed : "));
			Serial.println(error.f_str());
			return;
			rxDoc.clear();
		}

		Kp = rxDoc["P"];			  // 0
		Ki = rxDoc["I"];			  // 0
		Kd = rxDoc["D"];			  // 0
		baseMotorSpeed = rxDoc["ms"]; // 255
		loopDelay = rxDoc["de"];	  // 100
		rxDoc.clear();
		char buff[64];
		sprintf(buff, "W|P : %d | I : %d | D : %d | ms : %d | de : %d", P, I, D, baseMotorSpeed, loopDelay);
		Serial.println(buff);
	}
#endif

#if USE_INBUILT_BLUETOOTH == 1
	if (SerialBT.available())
	{

		SerialBT.flush();
		String data = SerialBT.readStringUntil('\n');

		SerialBT.printf("I|Data received : %s\n", data.c_str());

		DeserializationError error = deserializeJson(rxDoc, data);

		if (error)
		{
			SerialBT.printf("E|deseriaize json failed : %s\n", error.f_str());
			return;
			rxDoc.clear();
		}

		Kp = rxDoc["P"];			  // 0
		Ki = rxDoc["I"];			  // 0
		Kd = rxDoc["D"];			  // 0
		baseMotorSpeed = rxDoc["ms"]; // 255
		loopDelay = rxDoc["de"];	  // 100
		rxDoc.clear();

		SerialBT.printf("W|P : %d | I : %d | D : %d | ms : %d | de : %d\n", P, I, D, baseMotorSpeed, loopDelay);
	}
#endif

#endif
	// Step 1
	readSensors();

	// Step 2
	calculatePID();

	// Step 3
	controlMotors();
}
